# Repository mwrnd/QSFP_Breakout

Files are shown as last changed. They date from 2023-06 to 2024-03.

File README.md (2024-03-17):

**Work-In-Progress**: Design being tested. A second revision will be needed as the QSFP Cage Mounting pads are incorrect.

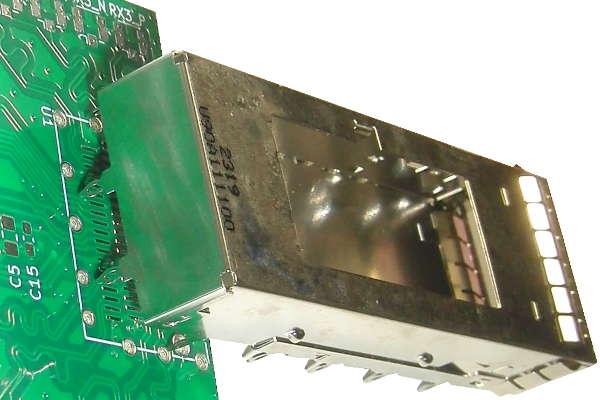
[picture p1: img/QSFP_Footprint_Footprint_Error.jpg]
QSFP Footprint Footprint Error


# QSFP Breakout

[QSFP](https://en.wikipedia.org/wiki/Small_Form-factor_Pluggable#QSFP) to [U.FL/UMCC Connector](https://en.wikipedia.org/wiki/Hirose_U.FL) breakout.

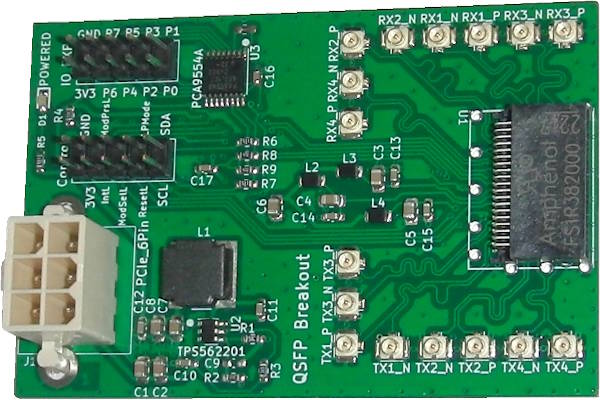
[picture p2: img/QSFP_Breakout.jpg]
QSFP Breakout Board


Additional I2C circuitry is due to this being a stepping stone project for an [OpenCAPI](https://files.openpower.foundation/s/xSQPe6ypoakKQdq/download/25Gbps-spec-20171108.pdf) to **dual** QSFP design. OpenCAPI has only a single I2C interface.

# PCB Layout

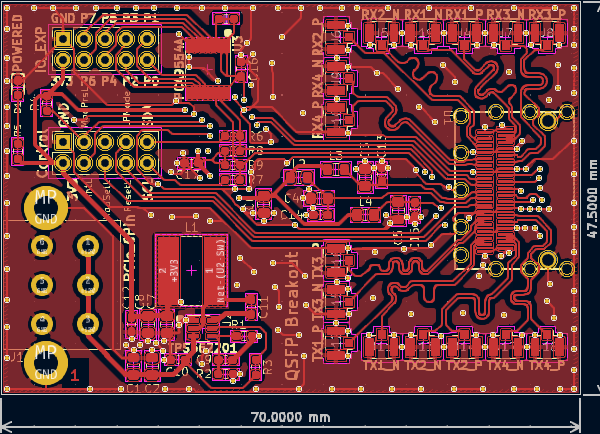
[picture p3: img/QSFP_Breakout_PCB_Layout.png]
QSFP Breakout PCB Layout


All differential signals are length-matched to within 1mm of a 25mm total length, both inter-pair and intra-pair.

# Schematic

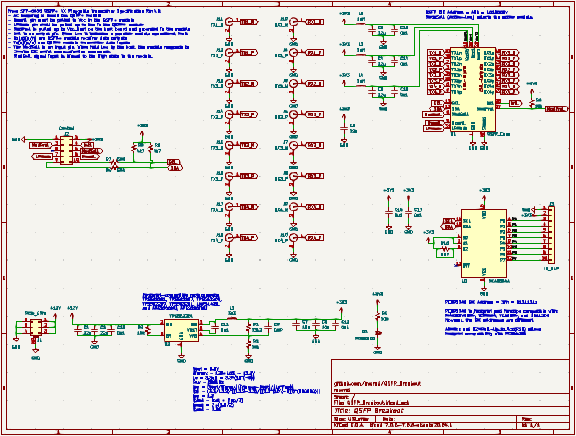
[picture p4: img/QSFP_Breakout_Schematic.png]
QSFP Breakout Schematic


# PCB Layer Stackup

4-Layer PCB stackup taken from [JLCPCB](https://jlcpcb.com/capabilities/pcb-capabilities).

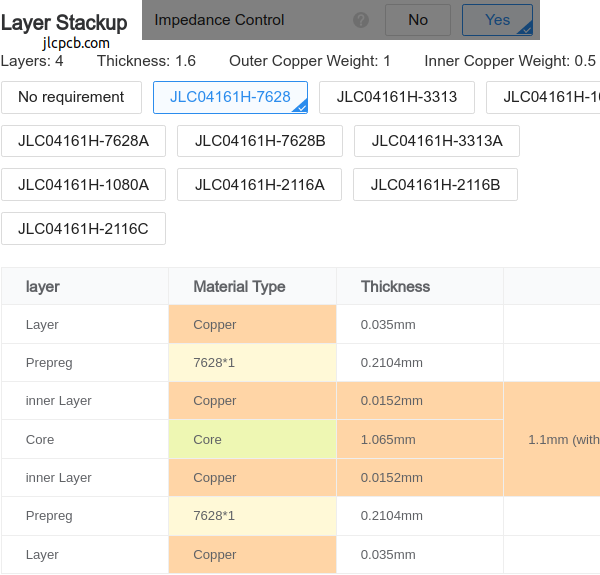
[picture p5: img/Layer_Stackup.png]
PCB Layer Stackup


100-ohm Differential Impedance parameters were calculated using the [DigiKey Online Calculator](https://www.digikey.com/en/resources/conversion-calculators/conversion-calculator-pcb-trace-impedance).

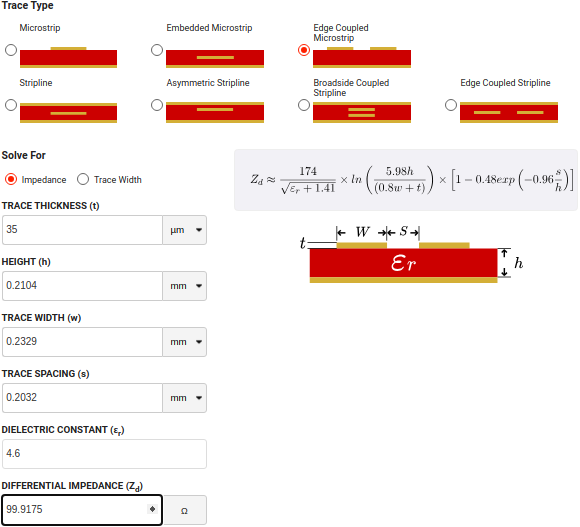
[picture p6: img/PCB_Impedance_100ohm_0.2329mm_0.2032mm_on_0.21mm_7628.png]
PCB Differential Impedance Calculation


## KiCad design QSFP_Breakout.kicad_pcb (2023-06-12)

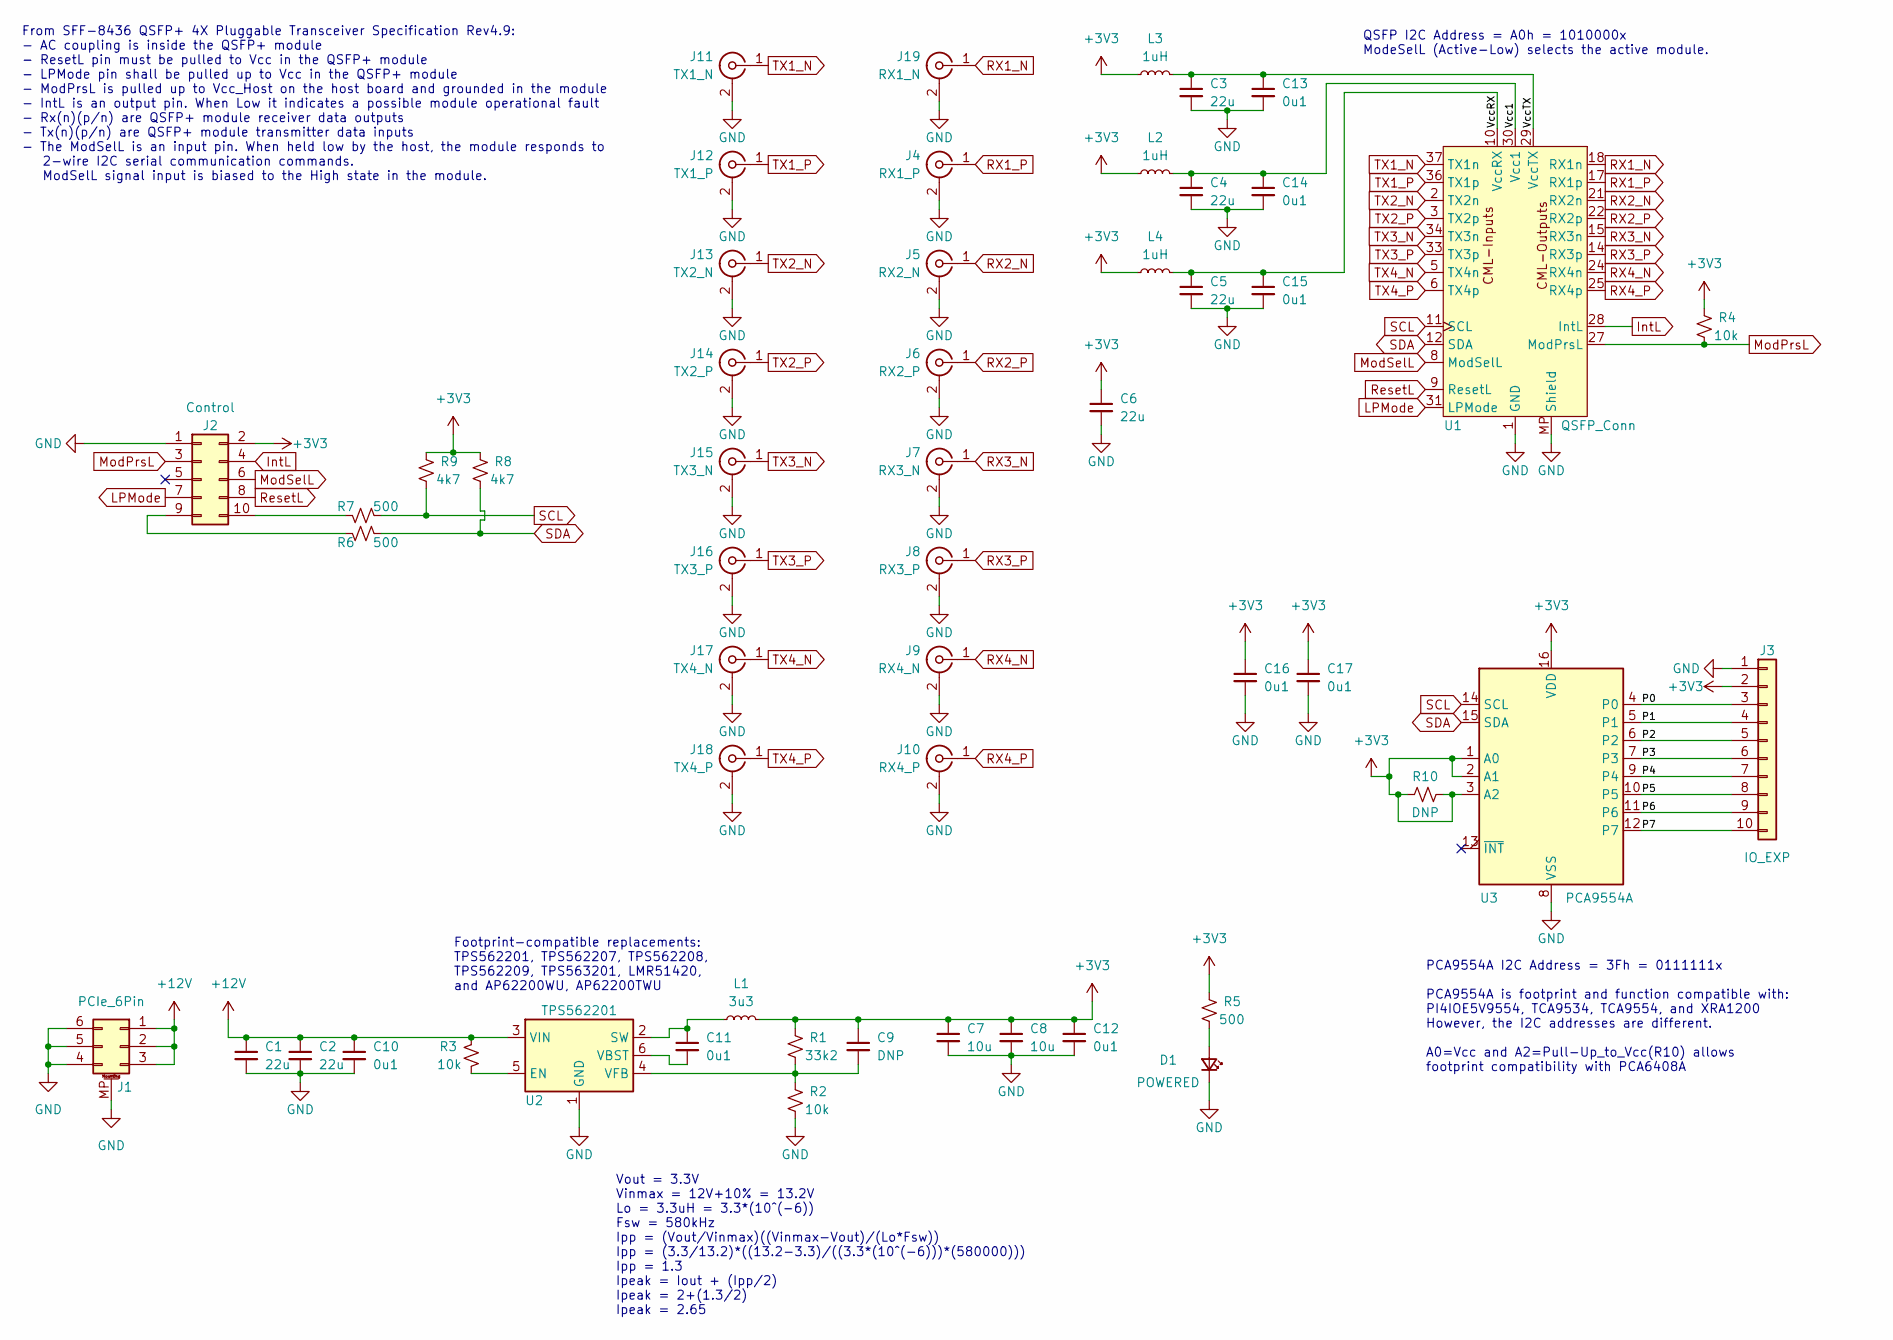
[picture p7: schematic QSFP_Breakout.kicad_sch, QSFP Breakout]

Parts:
C1, C2, C3, C4, C5, C6: 22u; C_0805_2012Metric_Pad1.18x1.45mm_HandSolder
C7, C8: 10u; C_0805_2012Metric_Pad1.18x1.45mm_HandSolder
C9: DNP; C_0603_1608Metric_Pad1.08x0.95mm_HandSolder
C10, C11, C12, C13, C14, C15, C16, C17: 0u1; C_0603_1608Metric_Pad1.08x0.95mm_HandSolder
D1: POWERED; D_0603_1608Metric_Pad1.05x0.95mm_HandSolder
J1: PCIe_6Pin; ATX_PCIe_6-Pin_Power_Board-Edge
J2: Control; PinSocket_2x05_P2.54mm_Vertical
J3: IO_EXP; PinSocket_2x05_P2.54mm_Vertical
J4: RX1_P; U.FL_Hirose_w_Label
J5: RX2_N; U.FL_Hirose_w_Label
J6: RX2_P; U.FL_Hirose_w_Label
J7: RX3_N; U.FL_Hirose_w_Label
J8: RX3_P; U.FL_Hirose_w_Label
J9: RX4_N; U.FL_Hirose_w_Label
J10: RX4_P; U.FL_Hirose_w_Label
J11: TX1_N; U.FL_Hirose_w_Label
J12: TX1_P; U.FL_Hirose_w_Label
J13: TX2_N; U.FL_Hirose_w_Label
J14: TX2_P; U.FL_Hirose_w_Label
J15: TX3_N; U.FL_Hirose_w_Label
J16: TX3_P; U.FL_Hirose_w_Label
J17: TX4_N; U.FL_Hirose_w_Label
J18: TX4_P; U.FL_Hirose_w_Label
J19: RX1_N; U.FL_Hirose_w_Label
L1: 3u3; L_Bourns-SRN8040_8x8.15mm
L2, L3, L4: 1uH; L_0805_2012Metric_Pad1.15x1.40mm_HandSolder
R1: 33k2; R_0603_1608Metric_Pad0.98x0.95mm_HandSolder
R2, R3, R4: 10k; R_0603_1608Metric_Pad0.98x0.95mm_HandSolder
R5, R6, R7: 500; R_0603_1608Metric_Pad0.98x0.95mm_HandSolder
R8, R9: 4k7; R_0603_1608Metric_Pad0.98x0.95mm_HandSolder
R10: DNP; R_0603_1608Metric_Pad0.98x0.95mm_HandSolder
U1: QSFP_Conn; QSFP_Conn_w_Cage
U2: TPS562201; SOT-23-6
U3: PCA9554A; TSSOP-16_4.4x5mm_P0.65mm

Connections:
+3V3: C6.1, C7.1, C8.1, C9.1, C12.1, C16.1, C17.1, J2.2, J3.2, L1.2, L2.1, L3.1, L4.1, R1.1, R4.1, R5.1, R8.1, R9.1, R10.1, R10.2, U3.1 (A0), U3.2 (A1), U3.3 (A2), U3.16 (VDD)
+12V: C1.1, C2.1, C10.1, J1.1, J1.2, J1.3, R3.1, U2.3 (VIN)
/P0: J3.3, U3.4 (P0)
/P1: J3.4, U3.5 (P1)
/P2: J3.5, U3.6 (P2)
/P3: J3.6, U3.7 (P3)
/P4: J3.7, U3.9 (P4)
/P5: J3.8, U3.10 (P5)
/P6: J3.9, U3.11 (P6)
/P7: J3.10, U3.12 (P7)
/Vcc1: C4.1, C14.1, L2.2, U1.30 (Vcc1)
/VccRX: C5.1, C15.1, L4.2, U1.10 (VccRX)
/VccTX: C3.1, C13.1, L3.2, U1.29 (VccTX)
GND: C1.2, C2.2, C3.2, C4.2, C5.2, C6.2, C7.2, C8.2, C10.2, C12.2, C13.2, C14.2, C15.2, C16.2, C17.2, D1.1 (K), J1.4, J1.5, J1.6, J1.MP (MountPin), J2.1, J3.1, J4.2 (Ext), J5.2 (Ext), J6.2 (Ext), J7.2 (Ext), J8.2 (Ext), J9.2 (Ext), J10.2 (Ext), J11.2 (Ext), J12.2 (Ext), J13.2 (Ext), J14.2 (Ext), J15.2 (Ext), J16.2 (Ext), J17.2 (Ext), J18.2 (Ext), J19.2 (Ext), R2.2, U1.1 (GND), U1.4 (GND), U1.7 (GND), U1.13 (GND), U1.16 (GND), U1.19 (GND), U1.20 (GND), U1.23 (GND), U1.26 (GND), U1.32 (GND), U1.35 (GND), U1.38 (GND), U1.MP (Shield), U2.1 (GND), U3.8 (VSS)
IntL: J2.4, U1.28 (IntL)
LPMode: J2.7, U1.31 (LPMode)
ModPrsL: J2.3, R4.2, U1.27 (ModPrsL)
ModSelL: J2.6, U1.8 (ModSelL)
unnamed: D1.2 (A), R5.2
unnamed: J2.9, R6.2
unnamed: J2.10, R7.2
unnamed: R3.2, U2.5 (EN)
unnamed: C11.1, L1.1, U2.2 (SW)
unnamed: C11.2, U2.6 (VBST)
unnamed: C9.2, R1.2, R2.1, U2.4 (VFB)
RX1_N: J19.1 (In), U1.18 (RX1n)
RX1_P: J4.1 (In), U1.17 (RX1p)
RX2_N: J5.1 (In), U1.21 (RX2n)
RX2_P: J6.1 (In), U1.22 (RX2p)
RX3_N: J7.1 (In), U1.15 (RX3n)
RX3_P: J8.1 (In), U1.14 (RX3p)
RX4_N: J9.1 (In), U1.24 (RX4n)
RX4_P: J10.1 (In), U1.25 (RX4p)
ResetL: J2.8, U1.9 (ResetL)
SCL: R7.1, R9.2, U1.11 (SCL), U3.14 (SCL)
SDA: R6.1, R8.2, U1.12 (SDA), U3.15 (SDA)
TX1_N: J11.1 (In), U1.37 (TX1n)
TX1_P: J12.1 (In), U1.36 (TX1p)
TX2_N: J13.1 (In), U1.2 (TX2n)
TX2_P: J14.1 (In), U1.3 (TX2p)
TX3_N: J15.1 (In), U1.34 (TX3n)
TX3_P: J16.1 (In), U1.33 (TX3p)
TX4_N: J17.1 (In), U1.5 (TX4n)
TX4_P: J18.1 (In), U1.6 (TX4p)

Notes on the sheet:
From SFF-8436 QSFP+ 4X Pluggable Transceiver Specification Rev4.9: - AC coupling is inside the QSFP+ module - ResetL pin must be pulled to Vcc in the QSFP+ module - LPMode pin shall be pulled up to Vcc in the QSFP+ module - ModPrsL is pulled up to Vcc_Host on the host board and grounded in the modu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
QSFP I2C Address = A0h = 1010000x ModeSelL (Active-Low) selects the active module.
Vout = 3.3V Vinmax = 12V+10% = 13.2V Lo = 3.3uH = 3.3*(10^(-6)) Fsw = 580kHz Ipp = (Vout/Vinmax)((Vinmax-Vout)/(Lo*Fsw)) Ipp = (3.3/13.2)*((13.2-3.3)/((3.3*(10^(-6)))*(580000))) Ipp = 1.3 Ipeak = Iout + (Ipp/2) Ipeak = 2+(1.3/2) Ipeak = 2.65
PCA9554A I2C Address = 3Fh = 0111111x PCA9554A is footprint and function compatible with: PI4IOE5V9554, TCA9534, TCA9554, and XRA1200 However, the I2C addresses are different. A0=Vcc and A2=Pull-Up_to_Vcc(R10) allows footprint compatibility with PCA6408A
Footprint-compatible replacements: TPS562201, TPS562207, TPS562208, TPS562209, TPS563201, LMR51420, and AP62200WU, AP62200TWU

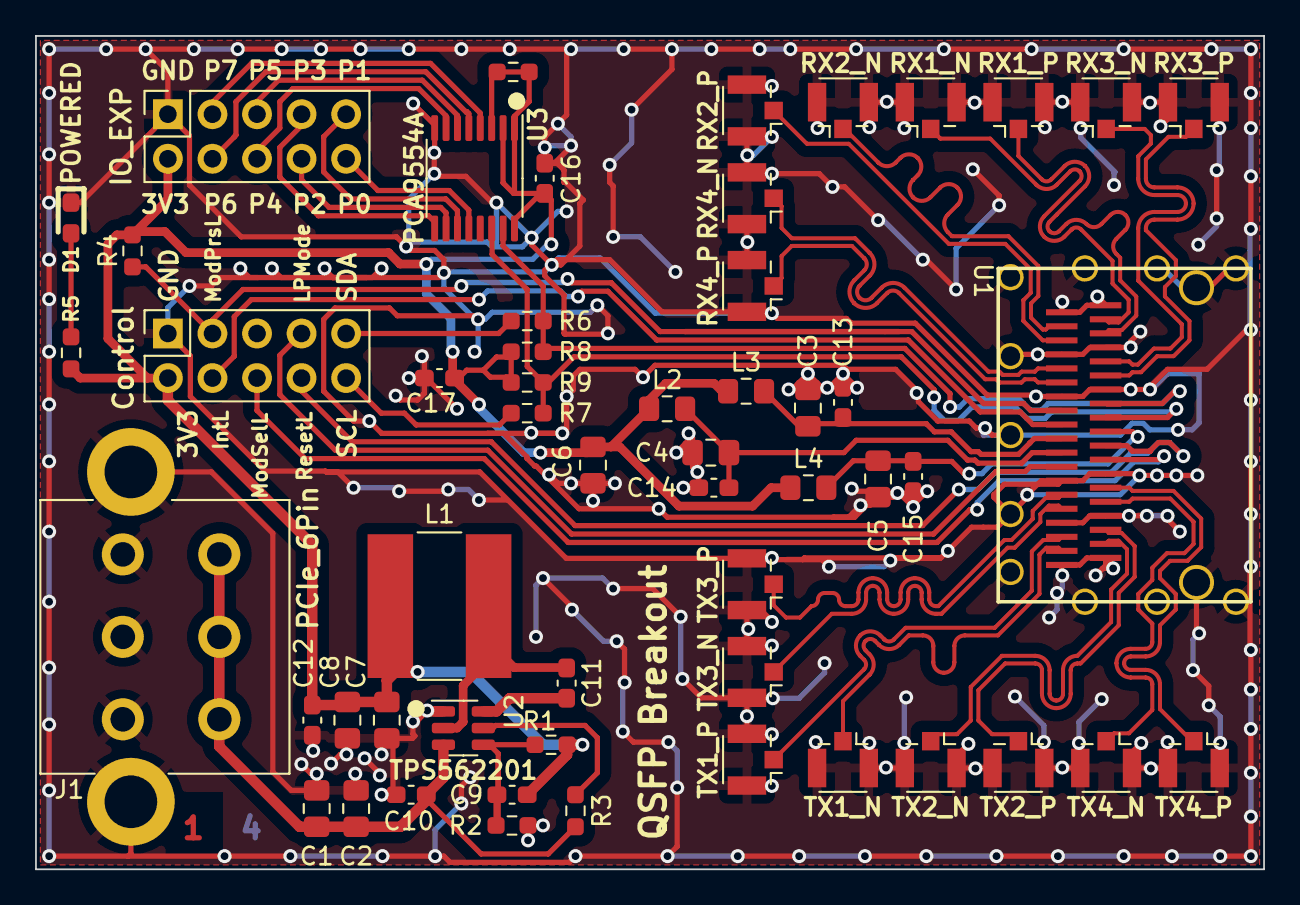
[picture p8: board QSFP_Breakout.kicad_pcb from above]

Board: 4 copper layers, 70.0 x 47.5 mm, 54 parts (0 on the bottom side), 44 nets.

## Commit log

2023-06-11 First Revision
    [QSFP_Breakout.kicad_pcb, QSFP_Breakout.kicad_sch]
2023-06-12 Updated GND Fill
    [QSFP_Breakout.kicad_pcb]
2023-06-12 v0.1.1 PCB Layout Image
